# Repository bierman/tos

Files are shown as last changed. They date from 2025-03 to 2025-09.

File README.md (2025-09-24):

# TOS Board Connection Map (v1.1)

## Raspberry Pi Connecter
| Raspberry Pi Physical Pin | GPIO Pin | TOS Connection | Description |
|---|---|---|---|
| 1 | 3.3v | 3.3v line (jumpered with pi pin 1) | 3.3v |
| 2 | 5v | 5v line (jumpered with pin 4) | 5v |
| 3 | GPIO 2 / SDA1 | Red LED through R1 (330 Ohm) | LED Red |
| 4 | 5v | 5v line (jumpered with pin 2) | 5v |
| 5 | GPIO 3 / SCL1 | NC | NC |
| 6 | GND | GND (all grounds jumpered) | Ground |
| 7 | GPIO 4 | NC | NC |
| 8 | GPIO 14 / TXD | MAX232 Pin 11 | TX TTL |
| 9 | GND | GND (all grounds jumpered) | Ground |
| 10 | GPIO 15 / RXD | MAX232 Pin 12 | RX TTL |
| 11 | GPIO 17 | Blue LED through R3 (220 Ohm) | LED Blue |
| 12 | GPIO 18 | NC | NC |
| 13 | GPIO 27 | Green LED through R2 (220 Ohm) | LED Green |
| 14 | GND | GND (all grounds jumpered) | Ground |
| 15 | GPIO 22 | SW1 - Pull up to 3.3v through R6 (4.7K Ohm) | Button |
| 16 | GPIO 23 | Keyboard pin 5 | PS2 Keyboard CLK |
| 17 | 3.3v | 3.3v line (jumpered with pi pin 17) | 3.3v |
| 18 | GPIO 24 | Keyboard Pin 1 | PS2 Keyboard Data |
| 19 | GPIO 10 / MOSI | PMOD pin 2 | PMOD 2 MOSI |
| 20 | GND | GND (all grounds jumpered) | Ground |
| 21 | GPIO 9 / MISO | PMOD pin 3 | PMOD 3 MISO |
| 22 | GPIO 25 | NC | NC |
| 23 | GPIO 11 / SCLK | PMOD pin 4 | PMOD 4 SCK |
| 24 | GPIO 8 / CE0 | PMOD pin 1 | PMOD 1 CS |
| 25 | GND | GND (all grounds jumpered) | Ground |
| 26 | GPIO 7 / CE1 | NC | NC |
| 27 | GPIO 0 / ID_SD (SDA0) | Mouse Pin 1 | PS2 Mouse Data |
| 28 | GPIO 1 / ID_SC (SCL0) | Mouse Pin 5 | PS2 Mouse CLK |
| 29 | GPIO 5 | NC | NC |
| 30 | GND | GND (all grounds jumpered) | Ground |
| 31 | GPIO 6 | NC | NC |
| 32 | GPIO 12 / PWM0 | PMOD pin 7 | PMOD7 - Int |
| 33 | GPIO 13 / PWM1 | NC | NC |
| 34 | GND | GND (all grounds jumpered) | Ground |
| 35 | GPIO 19 | NC | NC |
| 36 | GPIO 16 | PDOD pin 8 | PMOD8 - Reset |
| 37 | GPIO 26 | NC | NC |
| 38 | GPIO 20 / PCM_DIN | PMOD pin 9 | PMOD9 |
| 39 | GND | GND (all grounds jumpered) | Ground |
| 40 | GPIO 21 / PCM_DOUT | PMOD pin 10 | PMOD10 |

## RS-232 Connecter

| RS-232 Connector | GPIO Pin | TOS Connection | Description |
|---|---|---|---|
| 1 | | NC | NC |
| 2 | | MAX232 Pin 13 | RX |
| 3 | | MAX232 Pin 14 | TX |
| 4 | | NC | NC |
| 5 | | GND | Ground |
| 6 | | NC | NC |
| 7 | | Jumpered to RS232 Pin 8 | Jumpered to RS232 Pin 8 |
| 8 | | Jumpered to RS232 Pin 7 | Jumpered to RS232 Pin 7 |
| 9 | | NC | NC |

## MAX232 chip

| MAX232 | GPIO Pin | TOS Connection | Description |
|---|---|---|---|
| 1 | | C1+ (0.1uf) to MAX232 pin 3 | |
| 2 | | C4+ (0.1uf) to GND | |
| 3 | | C1- (0.1uf) to MAX232 pin 1 | |
| 4 | | C2+ (0.1uf) to MAX232 pin 5 | |
| 5 | | C2- (0.1uf) to MAX232 pin 4 | |
| 6 | | C3- (0.1uf) to GND | |
| 7 | | NC | NC |
| 8 | | NC | NC |
| 9 | | NC | NC |
| 10 | | GND | Ground |
| 11 | | PI Physical pin 8 | TXTTL |
| 12 | | Pi Physical Pin 10 | RXTTL |
| 13 | | RS232 Pin 2 | RX |
| 14 | | RS232 Pin 3 | TX |
| 15 | | GND | Ground |
| 16 | | 3.3v | 3.3v |

## PMOD Connecter

| PMOD | GPIO Pin | TOS Connection | Description |
|---|---|---|---|
| 1 | GPIO 8 / CE0 | Pi Physical Pin 24 | PMOD 1 - CS |
| 2 | GPIO 10 / MOSI | Pi Physical Pin 19 | PMOD 2 - MOSI |
| 3 | GPIO 9 / MISO | Pi Physical Pin 21 | PMOD 3  - MISO |
| 4 | GPIO 11 / SCLK | Pi Physical Pin 23 | PMOD 4 - SClock |
| 5 | | GND | Ground |
| 6 | | 3.3v | 3.3v |
| 7 | GPIO 12 / PWM0 | Pi Physical Pin 32 | PMOD 7 - INT |
| 8 | GPIO 16 | Pi Physical Pin 36 | PMOD 8 - RESET |
| 9 | GPIO 20 / PCM_DIN | Pi Physical Pin 38 | PMOD 9 |
| 10 | GPIO 21 / PCM_DOUT | Pi Physical Pin 40 | PMOD 10 |
| 11 | | GND | Ground |
| 12 | | 3.3v | 3.3v |

## PS2 Mouse Connecter

| PS2 Mouse | GPIO Pin | TOS Connection | Description |
|---|---|---|---|
| 1 | GPIO 0 / ID_SD (SDA0) | Pi Physical Pin 27 (pull up to 3.3v through R8 (2K Ohm) | PS2 Mouse Data |
| 2 | | NC | NC |
| 3 | | GND | Ground |
| 4 | | 5v | 5v |
| 5 | GPIO 1 / ID_SC (SCL0) | Pi Physical Pin 28 (pull up to 3.3v through R7 (2K Ohm) | PS2 Mouse Clock |
| 6 | | NC | NC |

## PS2 Keyboard Connecter

| PS2 Keyboard | GPIO Pin | TOS Connection | Description |
|---|---|---|---|
| 1 | GPIO 24 | Pi Physical Pin 18 (pull up to 3.3v through R5 (2K Ohm) | PS2 Keyboard Data |
| 2 | | NC | NC |
| 3 | | GND | Ground |
| 4 | | 5v | 5v |
| 5 | GPIO 23 | Pi Physical Pin 16 (pull up to 3.3v through R4 (2K Ohm) | PS2 Keyboard Clock |
| 6 | | NC | NC |

## Breakout Connecter

| Breakout | GPIO Pin | TOS Connection | Description |
|---|---|---|---|
| 1 | | GND | Ground |
| 2 | GPIO 22 | Pi Physical 15  / SW1 - Pull up to 3.3v through R6 (4.7K Ohm) | Button |
| 3 | GPIO 2 / SDA1 | Pi Physical Pin 3 | Red LED |
| 4 | GPIO 24 | Pi Physical Pin 18 / PS2 Keyboard pin 1 | PS2 Keyboar Data |
| 5 | GPIO 23 | Pi Physical Pin 16 / PS2 Keyboard pin 5 | PS2 Keyboard Clock |
| 6 | | RS-232 pin 4 | RX |
| 7 | | RS-232 pin 3 | TX |

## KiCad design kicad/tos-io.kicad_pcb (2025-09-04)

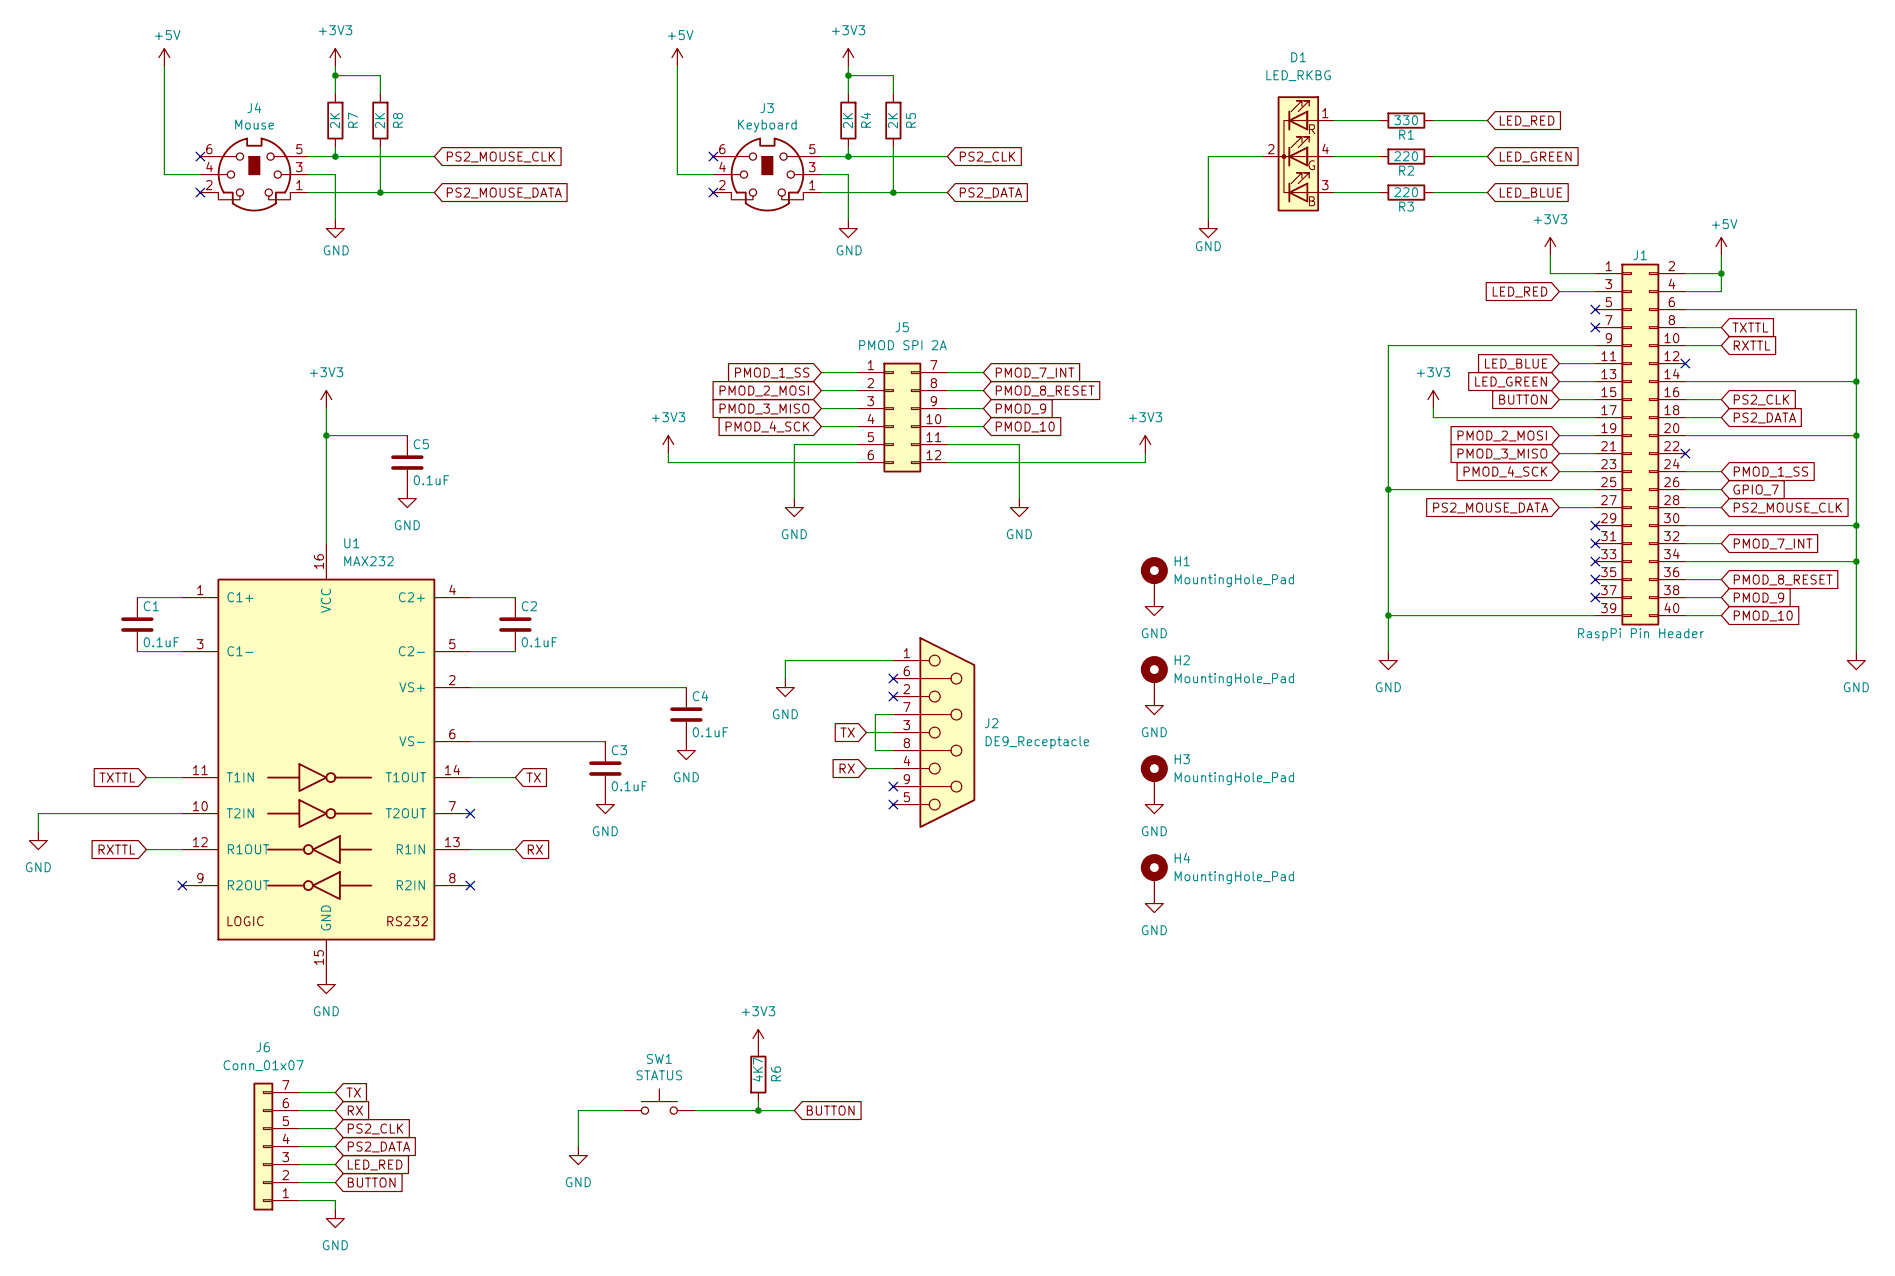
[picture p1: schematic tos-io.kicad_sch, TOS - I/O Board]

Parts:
C1, C2, C3, C4, C5: 0.1uF; C_0805_2012Metric_Pad1.18x1.45mm_HandSolder; LCSC C49678
D1: LED_RKBG; LED_D5.0mm-4_RGB
H1, H2, H3, H4: MountingHole_Pad; MountingHole_3mm_Pad_Via
J1: RaspPi Pin Header; PinHeader_2x20_P2.54mm_Vertical; LCSC C132439
J2: DE9_Receptacle; DSUB-9_Female_Horizontal_P2.77x2.84mm_EdgePinOffset7.70mm_H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
J3: Keyboard; minidin_6_ps2_pcb_mount; LCSC C77848
J4: Mouse; minidin_6_ps2_pcb_mount
J5: PMOD SPI 2A; PinSocket_2x06_Top_Bottom_P2.54mm_Vertical; LCSC C358728
J6: Conn_01x07; PinHeader_1x07_P2.54mm_Vertical; LCSC C5360900
R1: 330; R_0805_2012Metric_Pad1.20x1.40mm_HandSolder
R2, R3: 220; R_0805_2012Metric_Pad1.20x1.40mm_HandSolder
R4, R5, R7, R8: 2K; R_0805_2012Metric_Pad1.20x1.40mm_HandSolder
R6: 4K7; R_0805_2012Metric_Pad1.20x1.40mm_HandSolder
SW1: STATUS; SW_PUSH_6mm; LCSC C722960
U1: MAX232; TSSOP-16_4.4x5mm_P0.65mm; LCSC C406863

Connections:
+3V3: C5.1, J1.1, J1.17, J5.6, J5.12, R4.2, R5.2, R6.1, R7.2, R8.2, U1.16 (VCC)
+5V: J1.2, J1.4, J3.4, J4.4
BUTTON: J1.15, J6.2, R6.2, SW1.2
GND: C3.2, C4.2, C5.2, D1.2 (K), H1.1, H2.1, H3.1, H4.1, J1.6, J1.9, J1.14, J1.20, J1.25, J1.30, J1.34, J1.39, J2.1, J3.3, J4.3, J5.5, J5.11, J6.1, SW1.1, U1.10 (T2IN), U1.15 (GND)
GPIO_7: J1.26
LED_BLUE: J1.11, R3.1
LED_GREEN: J1.13, R2.1
LED_RED: J1.3, J6.3, R1.1
unnamed: D1.3 (BA), R3.2
unnamed: D1.4 (GA), R2.2
unnamed: D1.1 (RA), R1.2
unnamed: J2.7, J2.8
unnamed: C1.1, U1.1 (C1+)
unnamed: C1.2, U1.3 (C1-)
unnamed: C2.1, U1.4 (C2+)
unnamed: C2.2, U1.5 (C2-)
unnamed: C4.1, U1.2 (VS+)
unnamed: C3.1, U1.6 (VS-)
PMOD_1_SS: J1.24, J5.1
PMOD_2_MOSI: J1.19, J5.2
PMOD_3_MISO: J1.21, J5.3
PMOD_4_SCK: J1.23, J5.4
PMOD_7_INT: J1.32, J5.7
PMOD_8_RESET: J1.36, J5.8
PMOD_9: J1.38, J5.9
PMOD_10: J1.40, J5.10
PS2_CLK: J1.16, J3.5, J6.5, R4.1
PS2_DATA: J1.18, J3.1, J6.4, R5.1
PS2_MOUSE_CLK: J1.28, J4.5, R7.1
PS2_MOUSE_DATA: J1.27, J4.1, R8.1
RX: J2.4, J6.6, U1.13 (R1IN)
RXTTL: J1.10, U1.12 (R1OUT)
TX: J2.3, J6.7, U1.14 (T1OUT)
TXTTL: J1.8, U1.11 (T1IN)

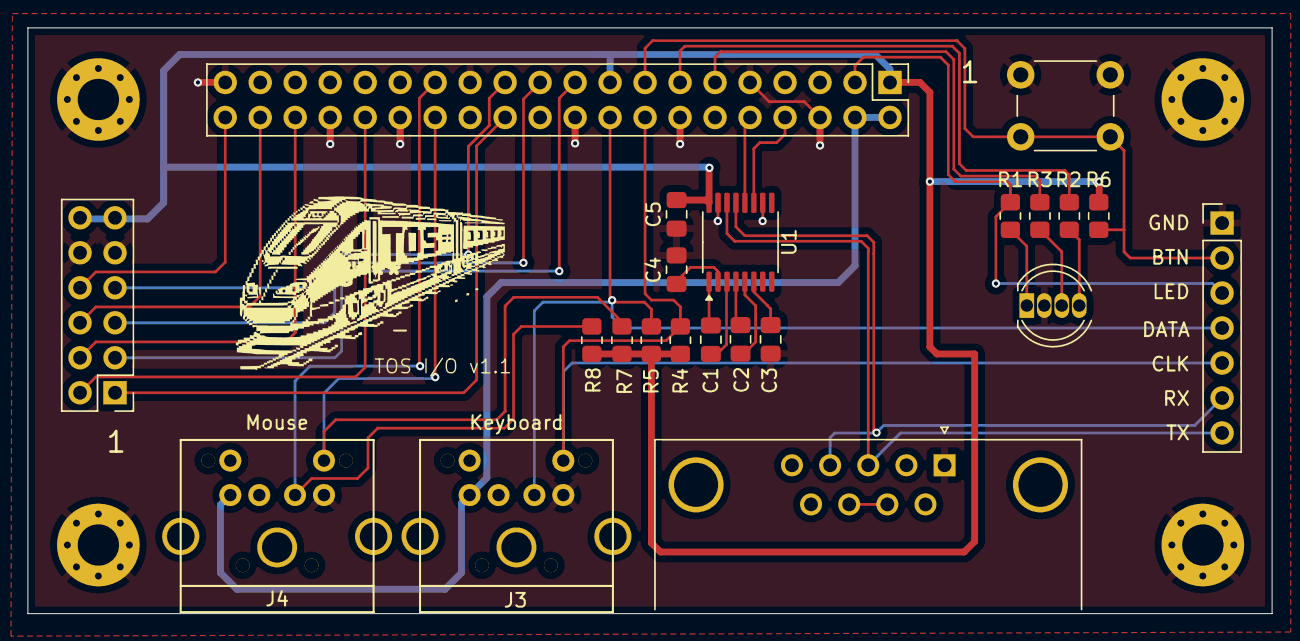
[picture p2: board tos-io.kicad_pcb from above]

Board: 2 copper layers, 90.3 x 42.5 mm, 26 parts (0 on the bottom side), 33 nets.

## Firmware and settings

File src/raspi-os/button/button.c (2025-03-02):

#include <stdio.h>
#include <stdlib.h>
#include <fcntl.h>
#include <unistd.h>
#include <sys/mman.h>
#include <stdint.h>

#include "tos-io.h"


#define GPIO_BASE 0xFE200000
#define BLOCK_SIZE 4096

#define GPIO_IN(g)  (*(gpio+((g)/10)) &= ~(7<<(((g)%10)*3)))
#define GPIO_OUT(g) (*(gpio+((g)/10)) |=  (1<<(((g)%10)*3)))
#define GPIO_SET(g) (*(gpio+7) = 1 << (g))
#define GPIO_CLR(g) (*(gpio+10) = 1 << (g))
#define GPIO_READ(g) (*(gpio+13) & (1 << (g)))

volatile unsigned *gpio;

void setup_io() {
  int mem_fd;
  void *gpio_map;

  if ((mem_fd = open("/dev/mem", O_RDWR | O_SYNC)) < 0) {
    perror("open");
    exit(EXIT_FAILURE);
  }

  gpio_map = mmap(
    NULL,
    BLOCK_SIZE,
    PROT_READ | PROT_WRITE,
    MAP_SHARED,
    mem_fd,
    GPIO_BASE
  );

  close(mem_fd);

  if (gpio_map == MAP_FAILED) {
    perror("mmap");
    exit(EXIT_FAILURE);
  }

  gpio = (volatile unsigned *) gpio_map;
}

int main(int argc, char** argv) {
  setup_io();

  GPIO_IN(TOS_IO_BUTTON);
  GPIO_OUT(TOS_IO_LED_RED);

  while (1) {
    if (!(GPIO_READ(TOS_IO_BUTTON))) { // Button pressed (active low)
      GPIO_SET(TOS_IO_LED_RED); // Turn on LED
    } else {
      GPIO_CLR(TOS_IO_LED_RED); // Turn off LED
    }
    usleep(10000);
  }

  return 0;
}

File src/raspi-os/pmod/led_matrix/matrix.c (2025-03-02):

#include <pigpio.h>
#include <pthread.h>
#include <stdio.h>
#include <stdbool.h>
#include "font.h"
#include <signal.h>

#include "tos-io.h"


static volatile bool running = true;


#define PIN_COL_0 TOS_IO_PMOD_IO2
#define PIN_COL_1 TOS_IO_PMOD_IO3
#define PIN_COL_2 TOS_IO_PMOD_IO4
#define PIN_ROW_0 TOS_IO_PMOD_IO6
#define PIN_ROW_1 TOS_IO_PMOD_IO7
#define PIN_ROW_2 TOS_IO_PMOD_IO8

static const int matrix[] = {PIN_COL_0, PIN_COL_1, PIN_COL_2, PIN_ROW_0, PIN_ROW_1, PIN_ROW_2};


static volatile uint64_t pattern = 0;

static int list_on[64] = {0};
static int last_on = 0;
static int current_on = 0;

static void* update(void* arg) {
  uint64_t last_pattern = 0;

  while (running) {
    if (pattern != last_pattern) {
      last_pattern = pattern;
      last_on = 0;
      current_on = 0;
      uint64_t p = pattern;

      // Look for LEDs that are on
      for (int i = 0; i < 64; i++) {
        bool on = p & 1;
        if (on) {
          list_on[last_on++] = i;
        }
        p >>= 1;
      }
    }

    for (int i = 0; i < last_on; i++) {
      int x = list_on[i];
      for (int k = 0; k < 6; k++) {
        gpioWrite(matrix[k], (x >> k) & 1);
      }
      gpioDelay(100);
    }
  }
  return NULL;
}

void handle_signal(int signal) {
  if (signal == SIGINT) {
    running = false;
  }
}

void ticker_tape(const char* msg) {
  const char* current_char = msg;
  uint64_t current_pattern = 0;
  uint64_t next_pattern = 0;
  while(running) {
    if (*current_char == '\0') {
      current_char = msg;
    }
    next_pattern = 0;
    for (int i = 0; i < 8; i++) {
      next_pattern <<= 8;
      next_pattern |= console_font_6x8[*current_char * 8 + i];
    }
    current_char++;
    for (int i = 0; i < 6; i++) {
      current_pattern <<= 1;
      current_pattern &= ~0x0101010101010101;
      for (int j = 0; j < 8; j++) {
        if (next_pattern & ((uint64_t) 0x80 << (j * 8))) {
          current_pattern |= (uint64_t) 1 << (j * 8);
        }
      }
      next_pattern <<= 1;
      pattern = current_pattern;
      gpioDelay(60000);
    }
  }
}

int main(void) {
  // Initialize pigpio and check for failure
  if (gpioInitialise() < 0) {
    printf("pigpio initialization failed\n");
    return 1;
  }

  // Set the LED pin as output
  for (int i = 0; i < 6; i++) {
    gpioSetMode(matrix[i], PI_OUTPUT);
  }
  signal(SIGINT, handle_signal);

  pthread_t thread_id;
  if (pthread_create(&thread_id, NULL, update, NULL) != 0) {
    printf("Failed to create thread\n");
    return 1;
  }

  ticker_tape("Hello, TOS!!! ");
  
  pthread_join(thread_id, NULL);

  gpioTerminate();
  return 0;
}

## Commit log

2025-02-06 TOS I/O KiCad schematics
    [tos-io.kicad_pcb, tos-io.kicad_sch]
2025-03-02 Button example for raspi-os using MMIO
2025-03-02 LED matrix example for raspi-os
2025-09-04 Add breakout header on TOS I/O board
    [tos-io.kicad_pcb, tos-io.kicad_sch]
2025-09-19 Update README with TOS Board Connection Map
2025-09-24 Update RS-232 Connector table in README.md
